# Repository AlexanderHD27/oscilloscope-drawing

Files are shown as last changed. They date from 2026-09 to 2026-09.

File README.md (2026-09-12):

# Oscilloscope Drawing

A device that draws on an oscilloscope.

## Introduction
Drawing on analog oscilloscope is almost a classic in the electronics/microcontroller community now.
This is done by setting the scope to XY-Mode and then controlling the X/Y-deflection of the electron-beam. My Scope has no Z-Channel. I cannot control the intensity of beam (or switches off) by voltage yet

This Project is my shot at this. I use custom hardware (build on perf-board) to archive this goal. I have build
a 2-Channel 16bit DAC with an refresh rate of around 1 MSample per second. Further more a usb-interface + driver shall be developed.

<p float="left">
  
  
  
</p>

My current todo list can be found [here](TODO.md)

### Hardware

Everything is solder onto pref-boards an connected via pin-headers and jumpers

<p float="left">
  
  
</p>



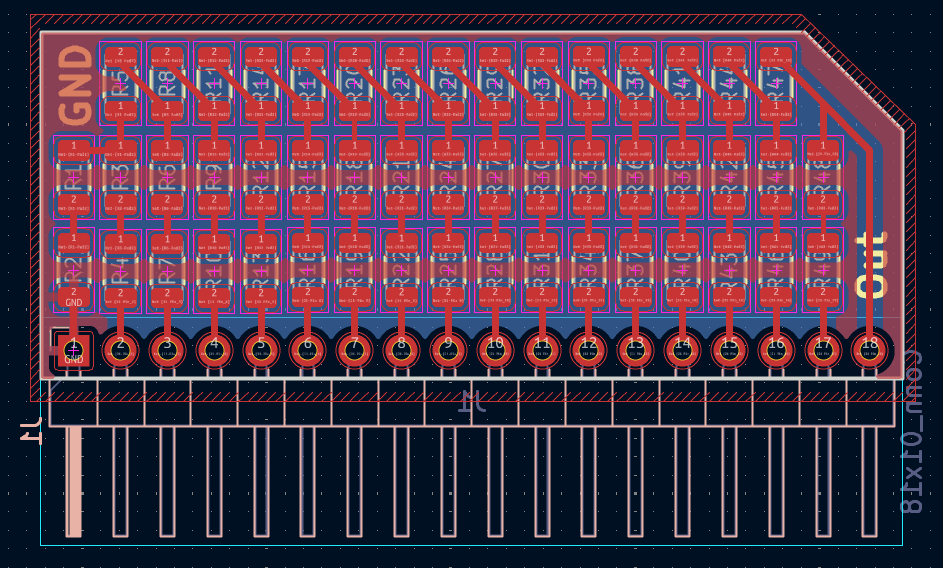
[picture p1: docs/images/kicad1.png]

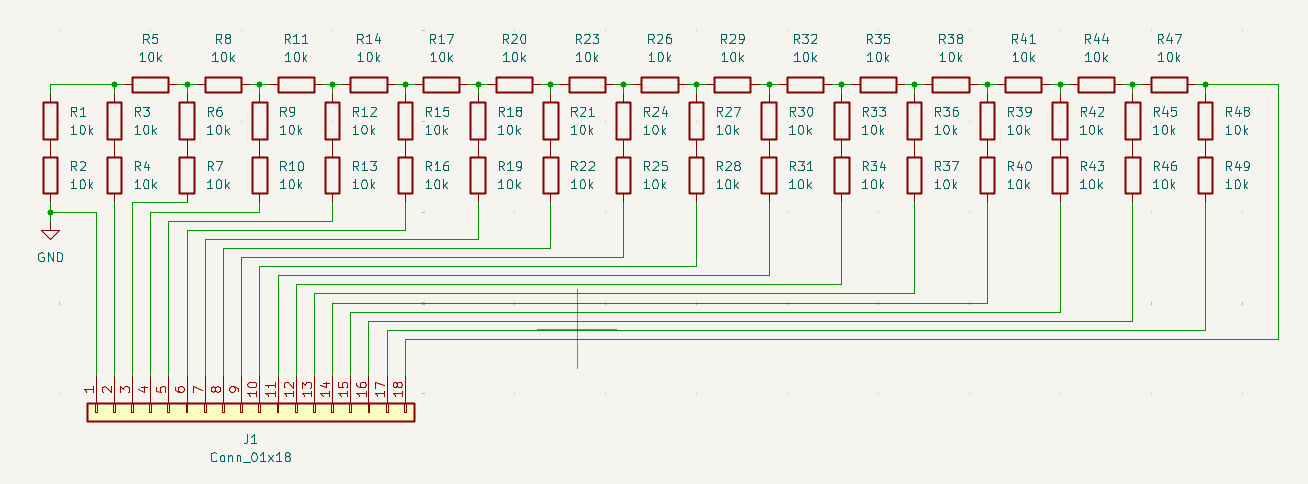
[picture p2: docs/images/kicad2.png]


(Diagram of the System-Hardware components)

The DACs are R-2R-Ladder DAC on a made custom PCB. The Input-Bits are feed from Octal-D-Latches ([74HC573](https://www.reichelt.de/oktal-d-type-latch-3-state-2--6-v-dil-20-74hc-573-p3264.html?search=74HC573)) in combination with some other logic ICs to reduce pin usage on the RPi Pico. Data sent via a 8-bit a parallel Bus to

<br>

At 1 MHz Square Wave, the analog output signal quality is significantly degraded. Testing revealed that probably R-2R_Ladder DAC is the weak link and needs further improvement. I currently use R = 11kOhm.



Yellow: X-Channel, Blue: Y-Channel, Magenta: Digital Input Signal to the DAC. (Yellow and Blue are coupled to AC, they usually to remove the 2.5V offset)

For testing the optics I did use a Hameg MH 312 Oscilloscope (I got this one used from Kleinanzeigen, so its already falling apart: semi-broken Coupling-switch, not being able focus the beam correctly, X-Pos nob falling off all the time)

### Further Components
- [Firmware](./firmware/README.md):

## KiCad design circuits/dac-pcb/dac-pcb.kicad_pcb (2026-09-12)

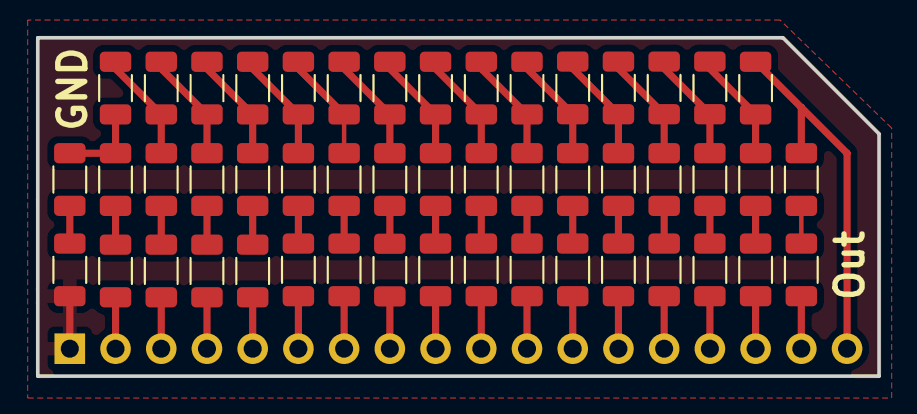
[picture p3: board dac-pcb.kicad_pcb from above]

Board: 2 copper layers, 46.7 x 18.8 mm, 50 parts (1 on the bottom side), 50 nets.

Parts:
J1: Conn_01x18; PinHeader_1x18_P2.54mm_Horizontal
R1, R2, R3, R4, R5, R6, R7, R8, R9, R10, R11, R12, R13, R14, R15, R16, R17, R18, R19, R20, R21, R22, R23, R24, R25, R26, R27, R28, R29, R30, R31, R32, R33, R34, R35, R36, R37, R38, R39, R40, R41, R42, R43, R44, R45, R46, R47, R48, R49: 10k; R_1206_3216Metric

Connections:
GND: J1.1, R2.2
unnamed: J1.2, R4.2
unnamed: J1.3, R7.2
unnamed: J1.4, R10.2
unnamed: J1.5, R13.2
unnamed: J1.6, R16.2
unnamed: J1.7, R19.2
unnamed: J1.8, R22.2
unnamed: J1.9, R25.2
unnamed: J1.10, R28.2
unnamed: J1.11, R31.2
unnamed: J1.12, R34.2
unnamed: J1.13, R37.2
unnamed: J1.14, R40.2
unnamed: J1.15, R43.2
unnamed: J1.16, R46.2
unnamed: J1.17, R49.2
unnamed: J1.18, R47.2, R48.1
unnamed: R1.1, R3.1, R5.1
unnamed: R1.2, R2.1
unnamed: R3.2, R4.1
unnamed: R5.2, R6.1, R8.1
unnamed: R6.2, R7.1
unnamed: R9.2, R10.1
unnamed: R8.2, R9.1, R11.1
unnamed: R11.2, R12.1, R14.1
unnamed: R12.2, R13.1
unnamed: R14.2, R15.1, R17.1
unnamed: R15.2, R16.1
unnamed: R17.2, R18.1, R20.1
unnamed: R18.2, R19.1
unnamed: R20.2, R21.1, R23.1
unnamed: R21.2, R22.1
unnamed: R23.2, R24.1, R26.1
unnamed: R24.2, R25.1
unnamed: R26.2, R27.1, R29.1
unnamed: R27.2, R28.1
unnamed: R29.2, R30.1, R32.1
unnamed: R30.2, R31.1
unnamed: R32.2, R33.1, R35.1
unnamed: R33.2, R34.1
unnamed: R35.2, R36.1, R38.1
unnamed: R36.2, R37.1
unnamed: R38.2, R39.1, R41.1
unnamed: R39.2, R40.1
unnamed: R41.2, R42.1, R44.1
unnamed: R42.2, R43.1
unnamed: R44.2, R45.1, R47.1
unnamed: R45.2, R46.1
unnamed: R48.2, R49.1
